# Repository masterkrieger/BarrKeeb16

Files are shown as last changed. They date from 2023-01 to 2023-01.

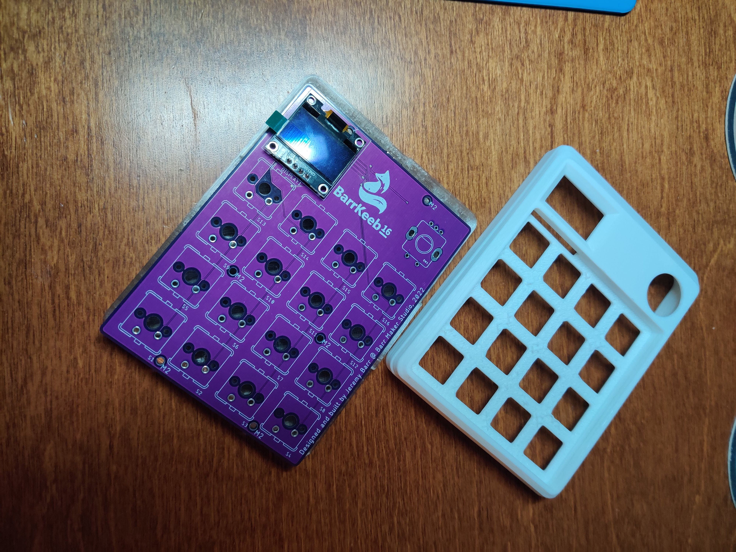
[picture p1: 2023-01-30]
Images/case_testing_fit.jpg

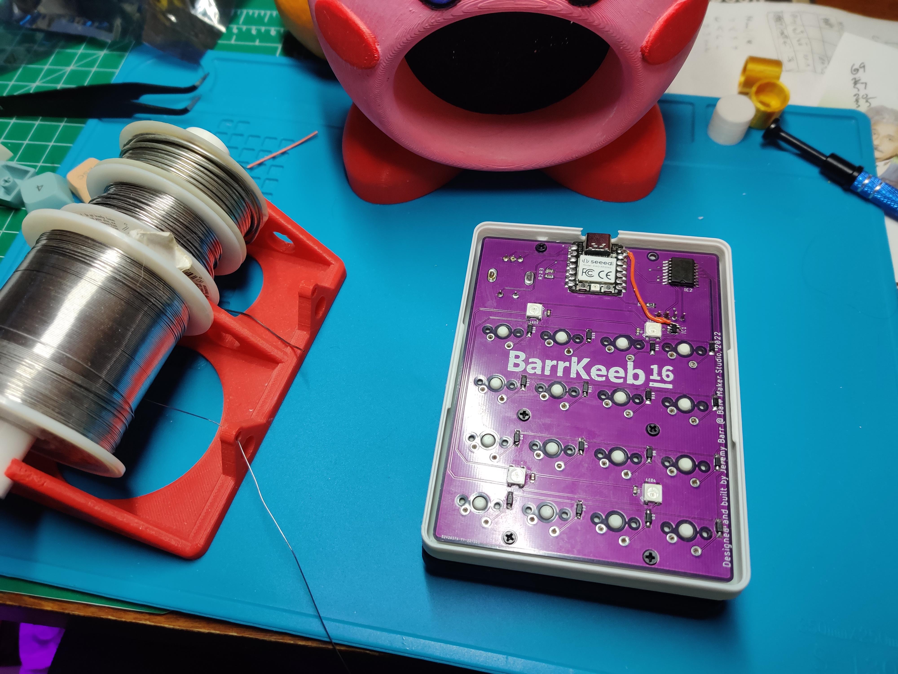
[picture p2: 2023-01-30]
Images/screwing_into_top_case.jpg

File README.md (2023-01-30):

# BarrKeeb16
 This is a 16 key macro keypad with a rotary encoder, OLED display and under-glow RGB. BarrKeeb16 is running KMK firmware on the Seeed XIAO RP2040.
 
BarrKeeb16_1
BarrKeeb16_2

# Parts
1. BarrKeeb16 custom PCB. [JLCPCB](https://jlcpcb.com/)
2. Seeed XIAO RP2040. [Digikey](https://www.digikey.com/en/products/detail/seeed-technology-co-ltd/102010428/14672129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) ― [SeeedStudio](https://www.seeedstudio.com/XIAO-RP2040-v1-0-p-5026.html)
3. 16 × Diodes (SOD-123) [Digikey](https://www.digikey.ca/en/products/detail/smc-diode-solutions/1N4148W/6022450)
4. 16 × Cherry MX style switches. [Digikey](https://www.digikey.ca/en/products/detail/adafruit-industries-llc/4952/14113453) ― [Adafruit](https://www.adafruit.com/product/4952)
5. 16 × DSA style keycaps. [Digikey](https://www.digikey.ca/en/products/detail/adafruit-industries-llc/4998/14552195) ― [Adafruit](https://www.adafruit.com/product/4998)
6. 1 × Encoder (PEC11R). [Digikey](https://www.digikey.ca/en/products/detail/bourns-inc/PEC11R-4215F-S0024/4499665) ― [Adafruit](https://www.adafruit.com/product/377)
7. 4 × Neopixel 5050 (SK6812 or WS2812 _ 5mm × 5mm) [Digikey](https://www.digikey.ca/en/products/detail/adafruit-industries-llc/1655/5154679) ― [Adafruit](https://www.adafruit.com/product/1655)
8. 4 × 0.1 µF Capacitors 0603 (1608 Metric). [Digikey](https://www.digikey.ca/en/products/detail/samsung-electro-mechanics/CL10B104KB8NNNL/3894274)
9. 1 × Level shifter SOT-23-5. [Digikey](https://www.digikey.ca/en/products/detail/texas-instruments/74AHCT1G125DBVTG4/1687957)
10. 1 × PCF8574 IO Expander. [Digikey](https://www.digikey.ca/en/products/detail/nxp-usa-inc/PCF8574T-3-512/735690)
10. 1 × 10 kOhms Resistor 0805 (2012 Metric). [Digikey](https://www.digikey.ca/en/products/detail/stackpole-electronics-inc/RMCF0805JG10K0/1757769)
10. 1 × 4.7 kOhms Resistor 0805 (2012 Metric). [Digikey](https://www.digikey.ca/en/products/detail/stackpole-electronics-inc/RMCF0805JT4K70/1757774)
11. 5 × Screws (M2 × 2.5mm)
12. 4 × Rubber Bumper Feet. [Adafruit](https://www.adafruit.com/product/550)

# OLED Image
 If you want to replace the BarrKeeb16_screenlogo bitmap, create any black and white 128x64 pixel image and rename as 'BarrKeeb16_screenlogo.bmp' or 'BarrKeeb16_screenlogo_inverted.bmp' or modify the image filename in [display_logo.py](https://github.com/masterkrieger/BarrKeeb16/blob/main/Firmware/display_logo.py).

## TODO:
- Update STL models with new OLED position (v1.2).
- Update FIRMWARE with new RP2040 and IO Expander pinouts (v1.2).

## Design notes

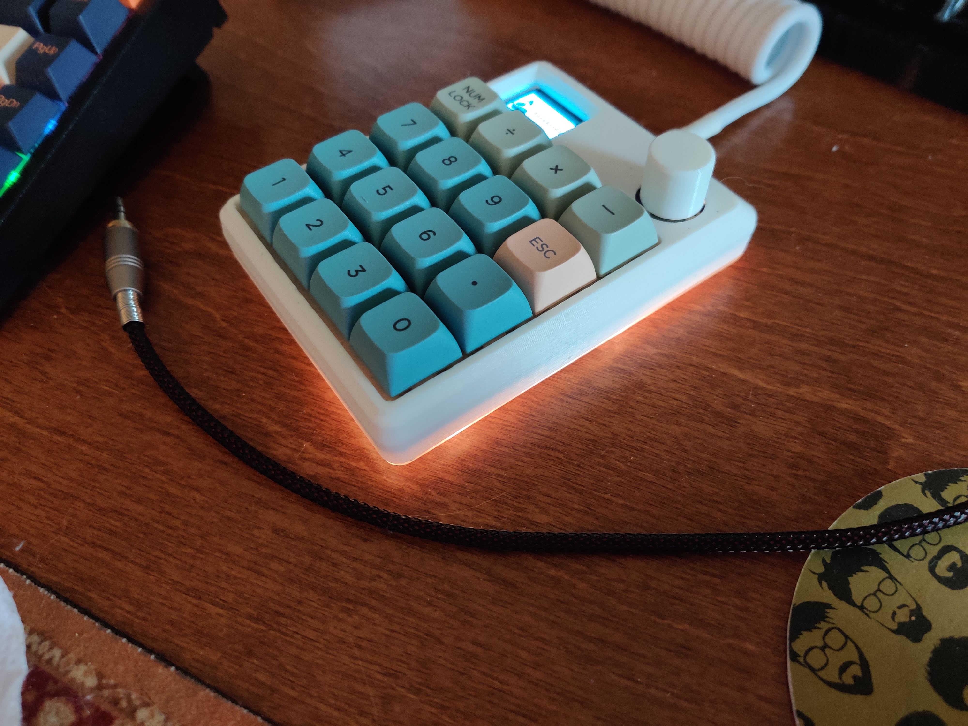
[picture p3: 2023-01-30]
Images/BarrKeeb16_2.jpg

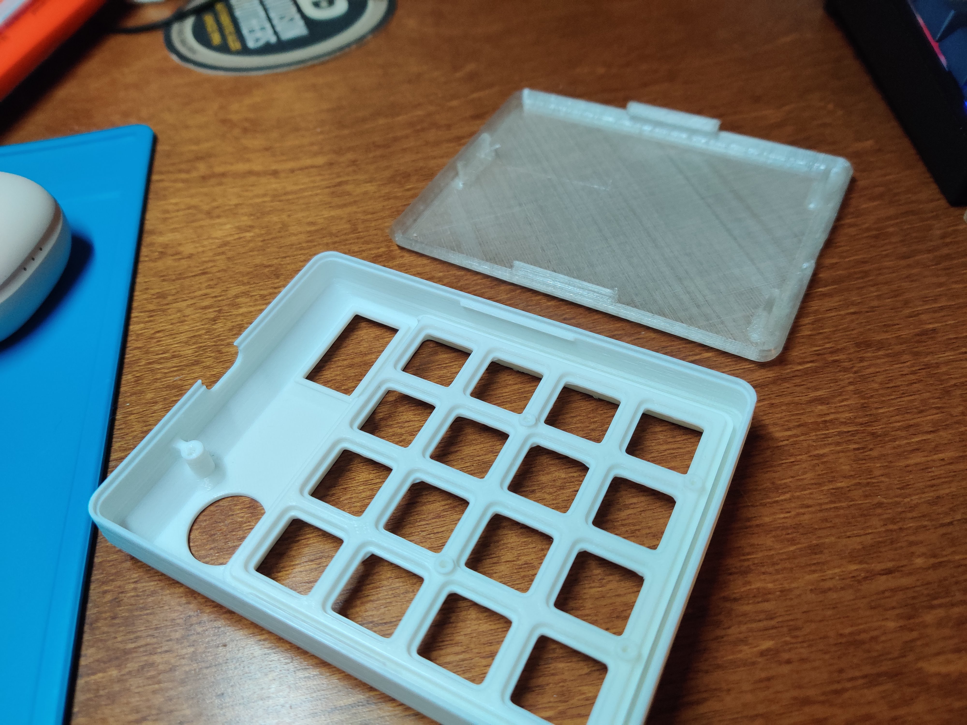
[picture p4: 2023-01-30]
Images/case_1.jpg

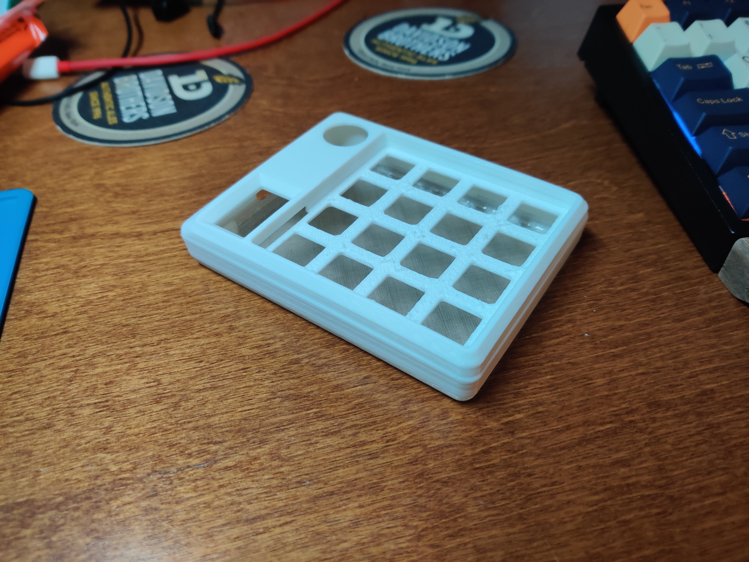
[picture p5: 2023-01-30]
Images/case_2.jpg

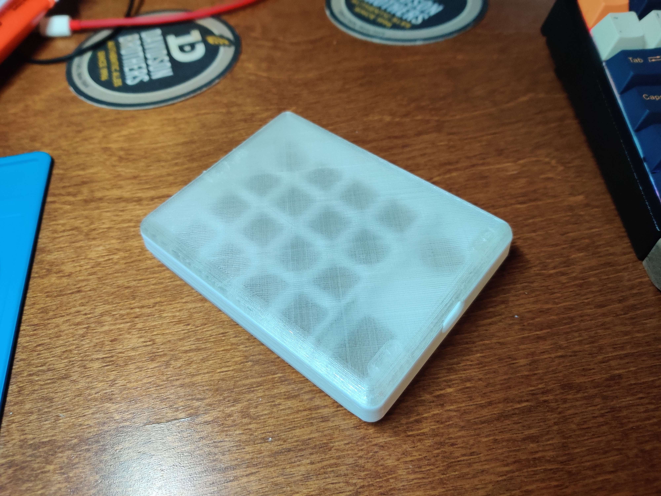
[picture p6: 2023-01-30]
Images/case_3.jpg

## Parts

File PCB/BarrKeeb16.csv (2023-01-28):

QTY | Value | Device | Package | Description | Digikey | QTY/Pack | Price | Link | Subtotal
4 | 0.1uF | 0.1UF-0603-25V-(+80/-20%) | 603 | 0.1µF ceramic capacitors | 276-CL10B104KB8NNNLCT-ND | 1 | 0.027 |  | 0.108
16 |  | MICROBUILDER_DIODESOD-123 | MICROBUILDER_SOD-123 | Diode | 1655-1360-1-ND | 1 | 0.124 |  | 1.984
1 | DIY-MODULES_DISPLAY-OLED-128X64-I2C | DIY-MODULES_DISPLAY-OLED-128X64-I2C | DIY-MODULES_DISPLAY-OLED-128X64-I2C | 128x64 Dot Matrix OLED Module based on SSD1306 chip | AOM12864A0-0.96WW-ANO | 1 | 1.35 | https://www.aliexpress.us/item/2251832770994631.html?_randl_shipto=US | 1.35
1 | 74HCT1G125DBV | 74AHC1G125DBV | SOT23-5 | Single Bus Buffer Gate with 3-State Output | 296-49526-1-ND | 1 | 0.95 |  | 0.95
1 | PCF8574T | PCF8574T | SO16W | I2C-Bus Remote 8-bit I/O expander | 568-1076-5-ND | 1 | 1.86 |  | 1.86
4 | WS2812B5050 | WS2812B5050 | WS2812B | NeoPixel 5050 RGB LED | 1528-2386-ND | 10 | 4.5 |  | 4.5
2 | 10K | R-US_R0805 | R0805 | RESISTOR, American symbol | RMCF0805JG10K0CT-ND | 1 | 0.018 |  | 0.036
1 | 4.7K | R-US_R0805 | R0805 | RESISTOR, American symbol | RMCF0805JG4K70CT-ND | 1 | 0.018 |  | 0.018
16 | CHERRY_MX | CHERRY_MX | CHERRY_MX | Cherry keymodule MX | 1528-4952-ND | 10 | 0.88 | https://www.aliexpress.us/item/3256803506501651.html?_randl_shipto=US | 1.76
1 |  | ADAFRUIT_ELECTROMECH_ENCODER_PLUS_SWITCH_BOURNS_PEC11 | ADAFRUIT_ELECTROMECH_PEC11+SWITCH | Rotary Encoder with Built-In Switch | PEC11R-4215F-S0024-ND | 1 | 1.88 |  | 1.88
1 | XIAO-RP2040 | XIAO-RP2040 | XIAO-SAMD21/RP2040-MODULE14P-2.54-21X17.8MM | Seeed Studio XIAO RP2040 v1.22 - Raspberry Pi RP2040 Microcontroller - 32-bit 133MHz Dual-Core ARM® Cortex® M0+processor Seeed SKU: 102010428 | 1597-102010428-ND | 1 | 5.4 | https://www.seeedstudio.com/XIAO-RP2040-v1-0-p-5026.html | 5.4
 |  |  |  |  |  |  |  | Total | 19.846

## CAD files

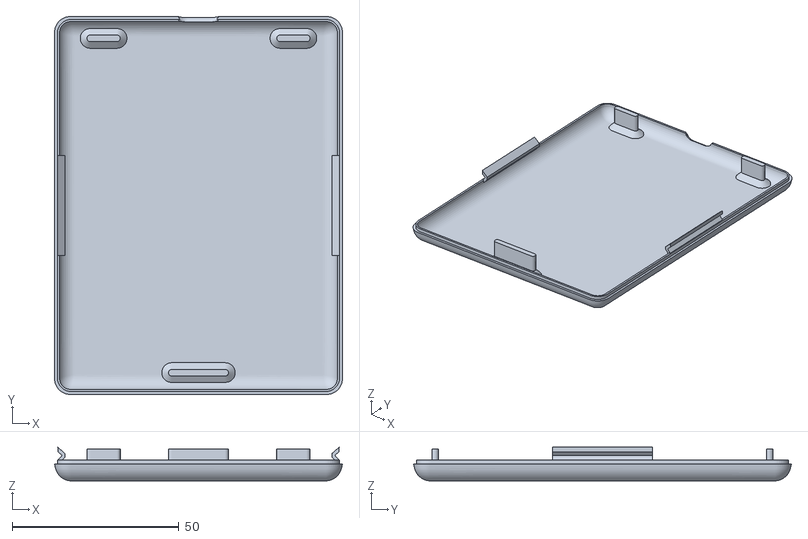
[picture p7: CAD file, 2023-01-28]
Models/BarrKeeb16_Bottom_Case.stl
86.4 x 113.4 x 10.1

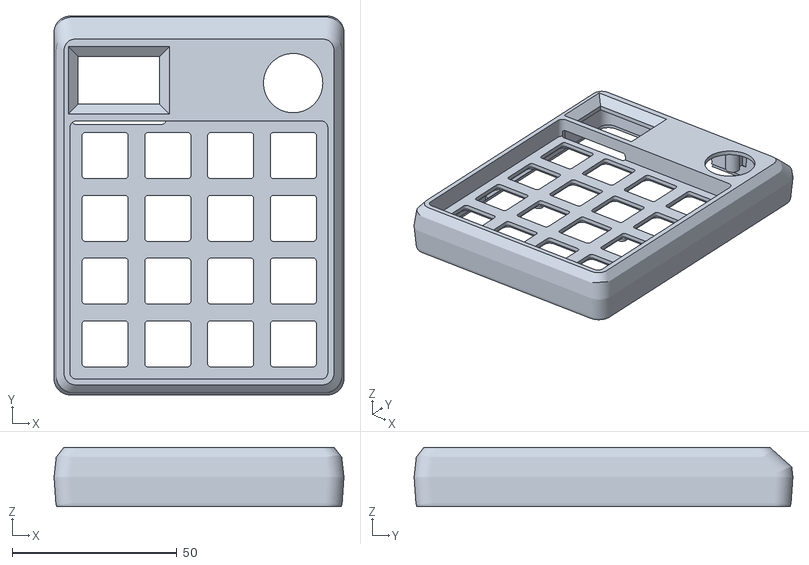
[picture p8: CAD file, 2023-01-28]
Models/BarrKeeb16_Top_Case.stl
88.0 x 115.0 x 18.0

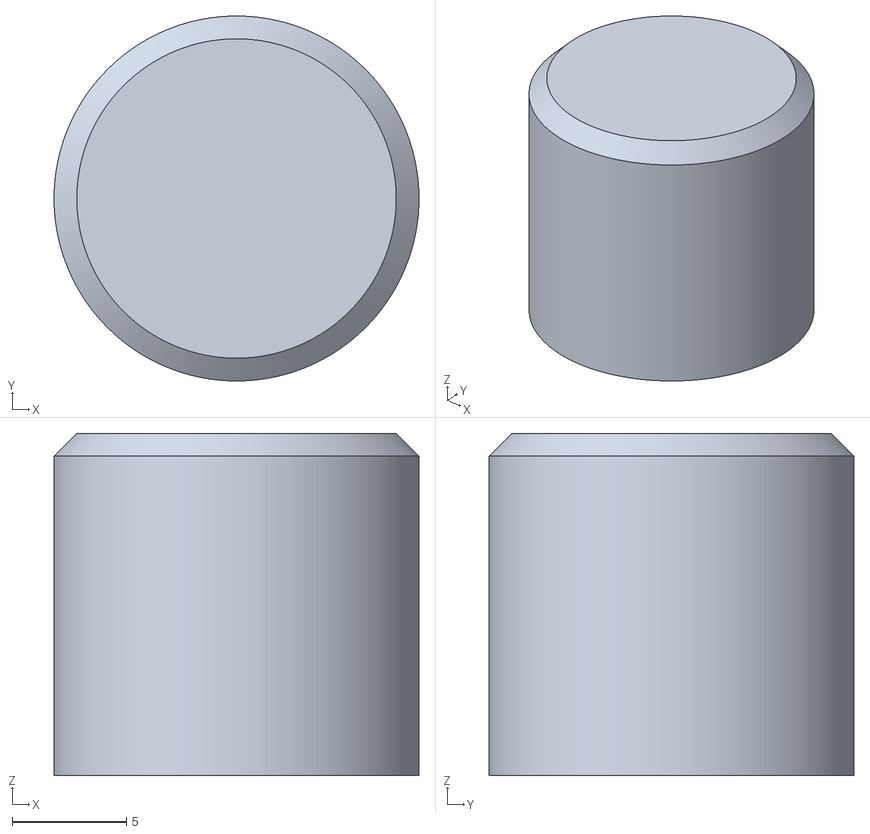
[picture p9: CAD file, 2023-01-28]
Models/Knob.stl
16.0 x 16.0 x 15.0

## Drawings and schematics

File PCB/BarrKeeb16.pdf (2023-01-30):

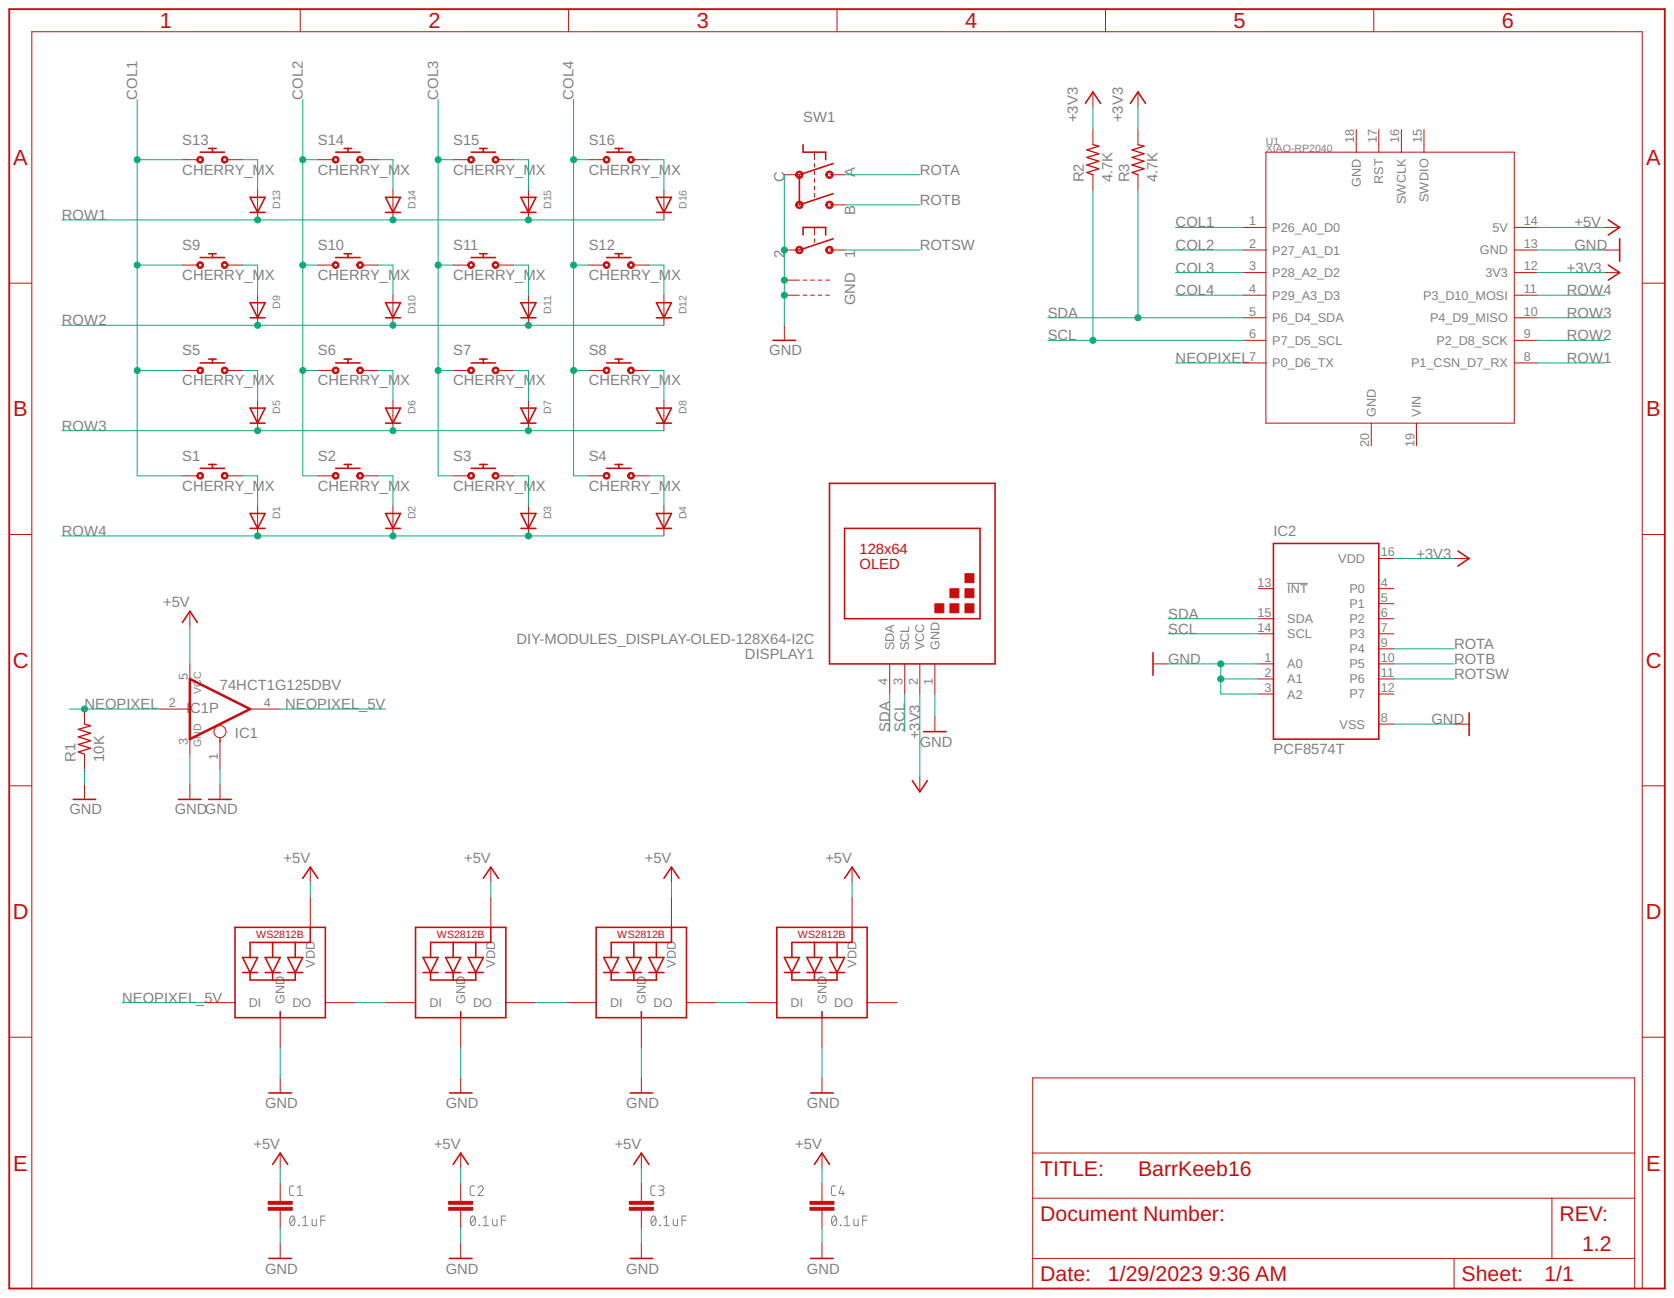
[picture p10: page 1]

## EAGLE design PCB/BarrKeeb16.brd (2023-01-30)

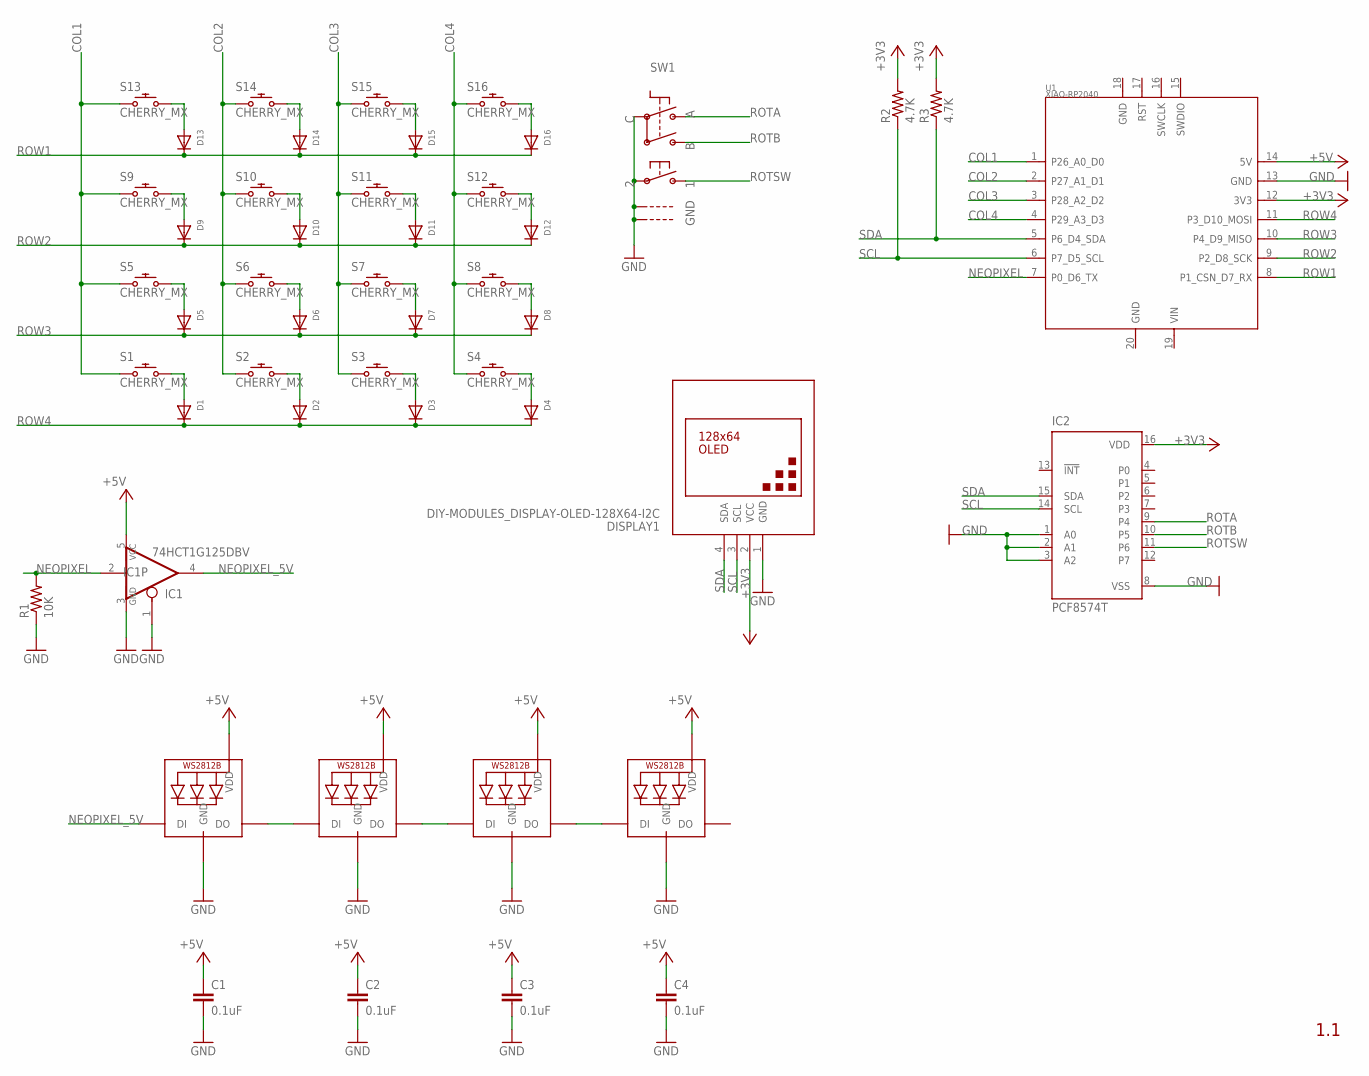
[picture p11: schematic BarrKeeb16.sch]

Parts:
C1, C2, C3, C4: 0.1uF; 0603
D1, D2, D3, D4, D5, D6, D7, D8, D9, D10, D11, D12, D13, D14, D15, D16: MICROBUILDER_DIODESOD-123; MICROBUILDER_SOD-123
DISPLAY1: DIY-MODULES_DISPLAY-OLED-128X64-I2C
IC1: 74HCT1G125DBV; SOT23-5
IC2: PCF8574T; SO16W
LED1, LED2, LED3, LED4: WS2812B5050; WS2812B
R1: 10K; R0805
R2, R3: 4.7K; R0805
S1, S2, S3, S4, S5, S6, S7, S8, S9, S10, S11, S12, S13, S14, S15, S16: CHERRY_MX
SW1: ADAFRUIT_ELECTROMECH_ENCODER_PLUS_SWITCH_BOURNS_P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; ADAFRUIT_ELECTROMECH_PEC11+SWITCH
U1: XIAO-RP2040; XIAO-SAMD21/RP2040-MODULE14P-2.54-21X17.8MM

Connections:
+3V3: DISPLAY1.2 (VCC), IC2.16 (VDD), R2.2, R3.2, U1.12 (3V3)
+5V: C1.1, C2.1, C3.1, C4.1, IC1.5 (VCC), LED1.1-VDD (VDD), LED2.1-VDD (VDD), LED3.1-VDD (VDD), LED4.1-VDD (VDD), U1.14 (5V)
COL1: S1.S1 (1), S5.S1 (1), S9.S1 (1), S13.S1 (1), U1.1 (P26_A0_D0)
COL2: S2.S1 (1), S6.S1 (1), S10.S1 (1), S14.S1 (1), U1.2 (P27_A1_D1)
COL3: S3.S1 (1), S7.S1 (1), S11.S1 (1), S15.S1 (1), U1.3 (P28_A2_D2)
COL4: S4.S1 (1), S8.S1 (1), S12.S1 (1), S16.S1 (1), U1.4 (P29_A3_D3)
GND: C1.2, C2.2, C3.2, C4.2, DISPLAY1.1 (GND), IC1.1 (OE), IC1.3 (GND), IC2.1 (A0), IC2.2 (A1), IC2.3 (A2), IC2.8 (VSS), LED1.3-GND (GND), LED2.3-GND (GND), LED3.3-GND (GND), LED4.3-GND (GND), R1.1, SW1.P$2, SW1.P$C, SW1.P$GND1, SW1.P$GND2, U1.13 (GND)
unnamed: D13.A, S13.S2 (2)
unnamed: D14.A, S14.S2 (2)
unnamed: LED1.2-DOUT (DO), LED2.4-DIN (DI)
unnamed: LED2.2-DOUT (DO), LED3.4-DIN (DI)
unnamed: LED3.2-DOUT (DO), LED4.4-DIN (DI)
unnamed: D15.A, S15.S2 (2)
unnamed: D16.A, S16.S2 (2)
unnamed: D9.A, S9.S2 (2)
unnamed: D10.A, S10.S2 (2)
unnamed: D11.A, S11.S2 (2)
unnamed: D12.A, S12.S2 (2)
unnamed: D5.A, S5.S2 (2)
unnamed: D6.A, S6.S2 (2)
unnamed: D7.A, S7.S2 (2)
unnamed: D8.A, S8.S2 (2)
unnamed: D1.A, S1.S2 (2)
unnamed: D2.A, S2.S2 (2)
unnamed: D3.A, S3.S2 (2)
unnamed: D4.A, S4.S2 (2)
NEOPIXEL: IC1.2 (I), R1.2, U1.7 (P0_D6_TX)
NEOPIXEL_5V: IC1.4 (O), LED1.4-DIN (DI)
ROTA: IC2.9 (P4), SW1.P$A
ROTB: IC2.10 (P5), SW1.P$B
ROTSW: IC2.11 (P6), SW1.P$1
ROW1: D13.C, D14.C, D15.C, D16.C, U1.8 (P1_CSN_D7_RX)
ROW2: D9.C, D10.C, D11.C, D12.C, U1.9 (P2_D8_SCK)
ROW3: D5.C, D6.C, D7.C, D8.C, U1.10 (P4_D9_MISO)
ROW4: D1.C, D2.C, D3.C, D4.C, U1.11 (P3_D10_MOSI)
SCL: DISPLAY1.3 (SCL), IC2.14 (SCL), R2.1, U1.6 (P7_D5_SCL)
SDA: DISPLAY1.4 (SDA), IC2.15 (SDA), R3.1, U1.5 (P6_D4_SDA)

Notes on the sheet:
1.1

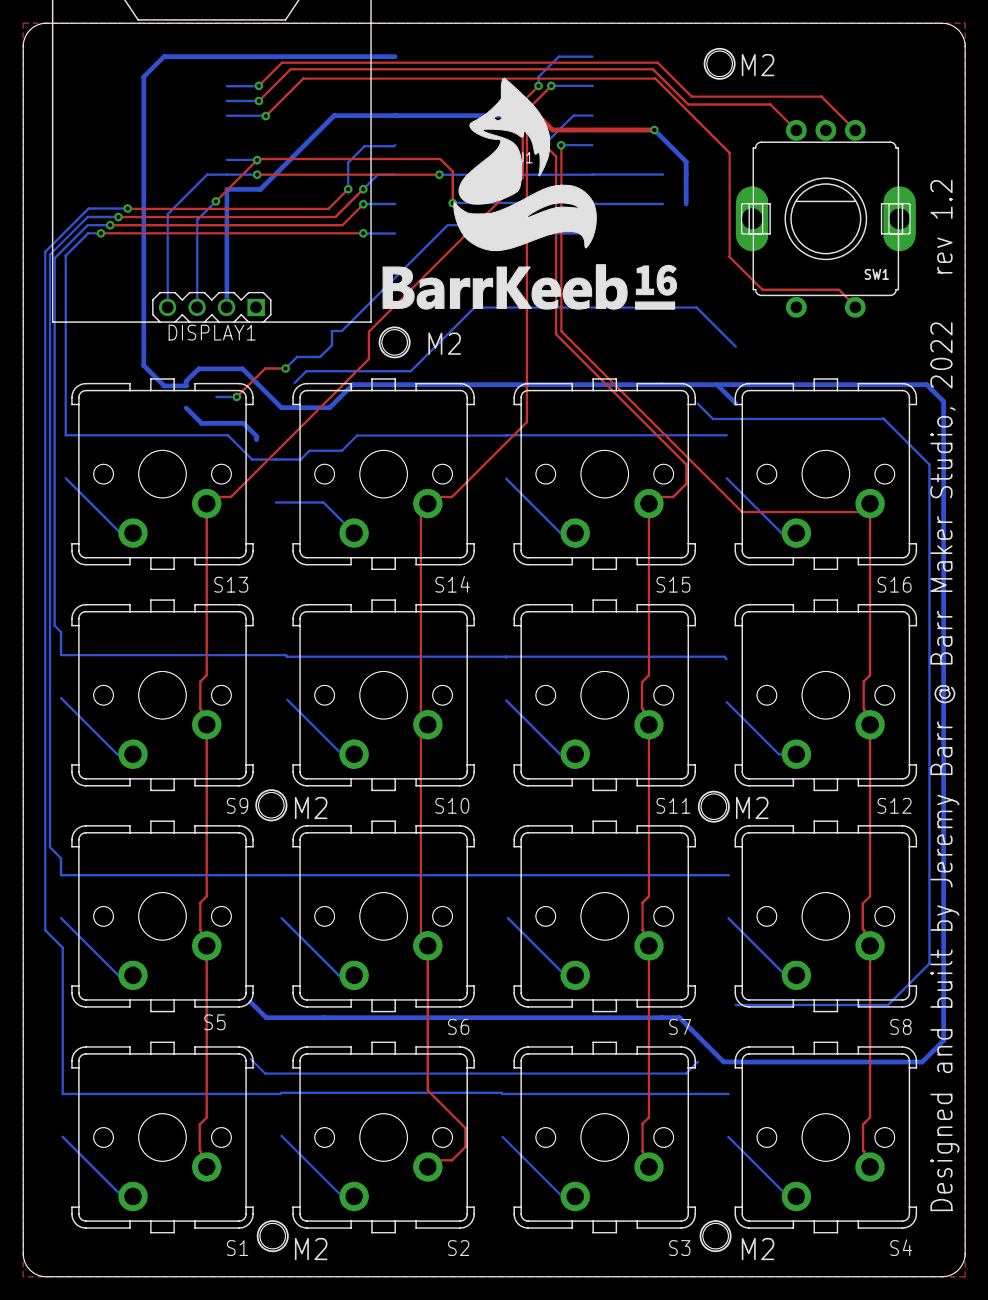
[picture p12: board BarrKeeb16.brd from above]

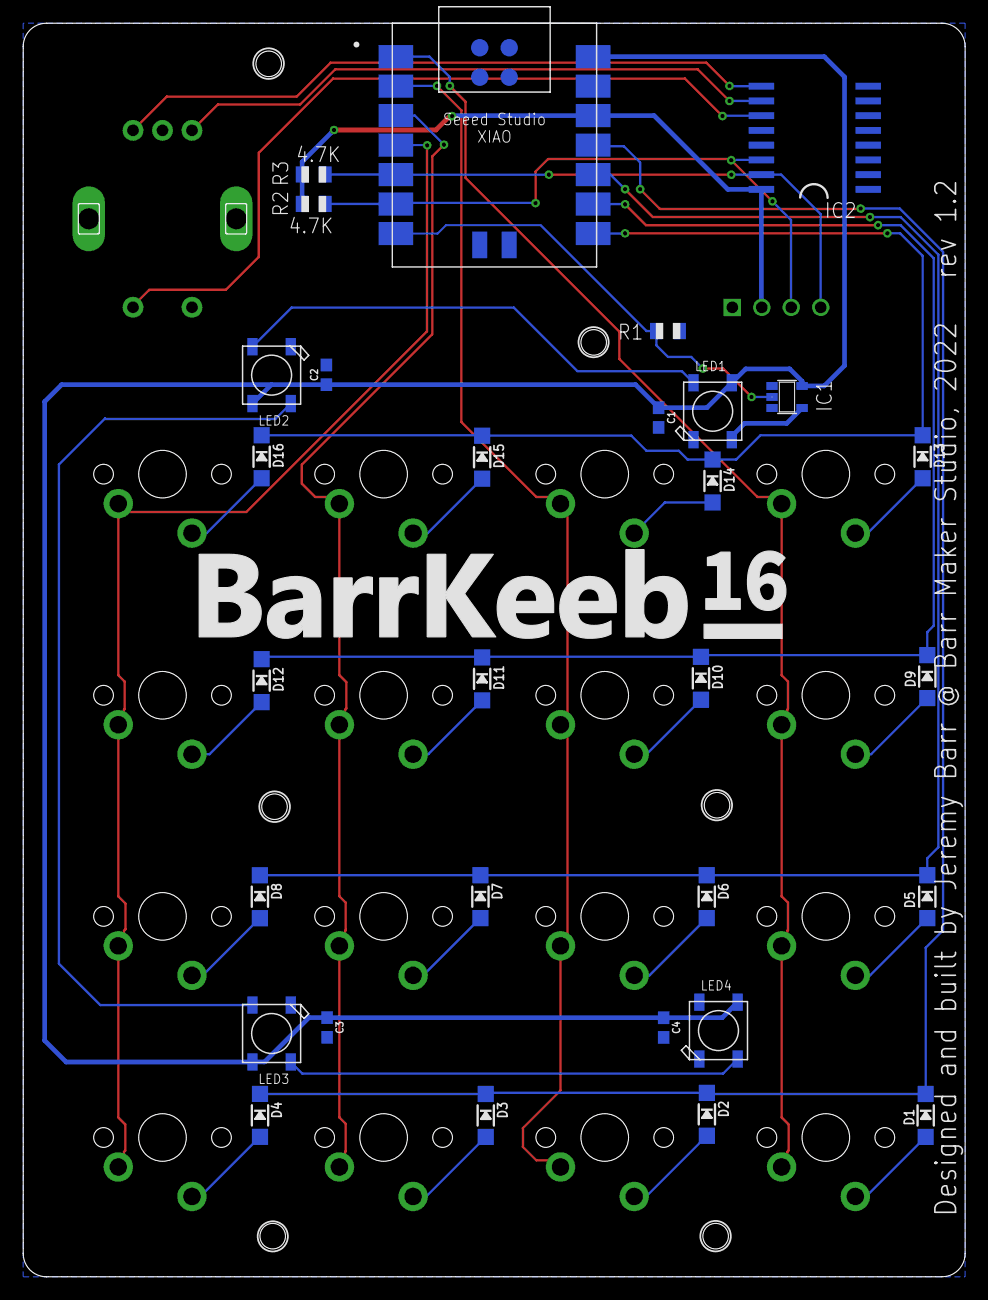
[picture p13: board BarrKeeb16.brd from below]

Board: 2 copper layers, 81.2 x 108.0 mm, 50 parts (31 on the bottom side), 37 nets.

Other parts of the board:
U$1: BARRKEEP16-LOGO
U$2: BARRKEEB-16

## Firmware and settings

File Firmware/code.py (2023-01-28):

######################
#  BarrKeeb16
#  version 1.0
#  28-Dec-2022
#  Author: Jeremy Barr
#
#  Notes:
#  kmk.matrix modified for PCF8574 output LOW when polling columns.
#  PCF8574 modified to read pin value as opposite value. KMK reads pin HIGH as keypress, but that's default input value.
######################

#print("Starting")

import board
import displayio

import adafruit_pcf8574  # modded library to work with KMK
import adafruit_displayio_ssd1306

import terminalio
import neopixel
from adafruit_display_text import label
from display_logo import display_splash_fox_inverted

from kmk.kmk_keyboard import KMKKeyboard
from kmk.keys import KC
from kmk.matrix import DiodeOrientation
from kmk.handlers.sequences import send_string, simple_key_sequence
from kmk.modules.layers import Layers as _Layers
from kmk.modules.encoder import EncoderHandler
from kmk.modules.tapdance import TapDance
from kmk.extensions.media_keys import MediaKeys
from kmk.extensions.RGB import RGB

# init IO Expander
pcf = adafruit_pcf8574.PCF8574(board.I2C(), address=0x20)

# KEYBOARD SETUP
#layers = Layers()
keyboard = KMKKeyboard()
encoders = EncoderHandler()
tapdance = TapDance()
tapdance.tap_time = 250
keyboard.modules = [encoders, tapdance]

# SWITCH MATRIX
keyboard.col_pins = (pcf.get_pin(4), pcf.get_pin(5), pcf.get_pin(6), pcf.get_pin(7))
keyboard.row_pins = (pcf.get_pin(0), pcf.get_pin(1), pcf.get_pin(2), pcf.get_pin(3))
keyboard.diode_orientation = DiodeOrientation.ROWS

# ENCODERS
encoders.pins = ((board.A0, board.A1, board.A2, False),)

# EXTENSIONS
rgb_ext = RGB(pixel_pin = board.D3, num_pixels=4)#, hue_default=100)
keyboard.extensions = [rgb_ext, MediaKeys()]

# custom functions
class Layers(_Layers):
    last_top_layer = 0
    hues = (4, 20, 69)
    
    def after_hid_send(keyboard):
        print(keyboard.active_layers[0])
        if keyboard.active_layers[0] != self.last_top_layer:
            self.last_top_layer = keyboard.active_layers[0]
            rgb.set_hsv_fill(self.hues[self.last_top_layer], 255, 255)
            display_layer_text(keyboard.active_layers[0])
            #print(keyboard.active_layers[0])
            
keyboard.modules.append(Layers())

keyboard.debug_enabled = False

# MACROS Layer 1
WIN_RIGHT = simple_key_sequence([KC.LGUI(KC.RIGHT), KC.MACRO_SLEEP_MS(100), KC.ESC])
WIN_LEFT = simple_key_sequence([KC.LGUI(KC.LEFT), KC.MACRO_SLEEP_MS(100), KC.ESC])
WIN_UP = simple_key_sequence([KC.LGUI(KC.UP)])
WIN_MIN = simple_key_sequence([KC.LGUI(KC.M)])
WIN_MAX = simple_key_sequence([KC.LGUI(KC.LSFT(KC.M))])
DESK_RIGHT = simple_key_sequence([KC.LCMD(KC.LCTRL(KC.RIGHT))])
DESK_LEFT = simple_key_sequence([KC.LCMD(KC.LCTRL(KC.LEFT))])
WIN_TAB = simple_key_sequence([KC.LCMD(KC.TAB)])
COPY = KC.LCTRL(KC.C)
PASTE = KC.LCTRL(KC.V)
POWERSHELL = simple_key_sequence([KC.LCMD(KC.R), KC.MACRO_SLEEP_MS(250), send_string('powershell'), KC.ENTER])

# NEOPIXEL RGB
#RGB_COLORS = KC.TD(Color.RED, Color.GREEN, Color.BLUE, Color.WHITE, Color.YELLOW, Color.ORANGE)
#TODO: change to NEOPIXEL functions
# Color_RED = rgb_ext.set_hsv_fill(0,100,100)
# Color_BLUE = rgb_ext.set_hsv_fill(240,100,100)
# Color_MAGENTA = rgb_ext.set_hsv_fill(300,100,100)
# Color_ORANGE = rgb_ext.set_hsv_fill(30,100,100)
# Color_WHITE = rgb_ext.set_hsv_fill(0,0,100)
# Color_GREEN = rgb_ext.set_hsv_fill(120,100,100)

_______ = KC.TRNS
xxxxxxx = KC.NO

# LAYER SWITCHING TAP DANCE
#TD_LYRS_1 = KC.TD(KC.KP_ENTER, KC.TO(1), KC.TO(2), KC.TO(0))
TD_LYRS_0 = KC.TD(KC.KP_ENTER, KC.TO(0))
TD_LYRS_1 = KC.TD(KC.KP_ENTER, KC.TO(1))
TD_LYRS_2 = KC.TD(KC.KP_ENTER, KC.TO(2))
RGB_LYRS = KC.TD(KC.RGB_MODE_PLAIN, KC.RGB_MODE_SWIRL, KC.RGB_MODE_KNIGHT, KC.RGB_MODE_RAINBOW, KC.RGB_MODE_BREATHE_RAINBOW)

# KEYMAPS
keyboard.keymap = [
    [  # Layer 0: WIN MACROS
        TD_LYRS_1, POWERSHELL,   WIN_TAB,    RGB_LYRS,
        WIN_UP,    KC.MPRV,      KC.MNXT,    KC.MPLY,
        WIN_LEFT,  WIN_RIGHT,    WIN_MIN,    WIN_MAX,
        COPY,      PASTE,        DESK_LEFT,  DESK_RIGHT ,
    ],
    [  # Layer 1: NUMPAD
        TD_LYRS_2,   KC.KP_SLASH,   KC.KP_ASTERISK,   KC.KP_MINUS,
        KC.P7,       KC.P8,         KC.P9,            KC.KP_PLUS,
        KC.P4,       KC.P5,         KC.P6,            KC.PDOT,
        KC.P1,       KC.P2,         KC.P3,            KC.P0,
    ],
    [  # Layer 2: RGB CTL
        TD_LYRS_0,          KC.RGB_HUI,          KC.RGB_VAI,                   KC.RGB_ANI,
        KC.RGB_SAI,         KC.RGB_HUD,          KC.RGB_VAD,                   KC.RGB_AND,    
        KC.RGB_MODE_SWIRL,  KC.RGB_MODE_KNIGHT,  KC.RGB_MODE_BREATHE_RAINBOW,  KC.RGB_SAI,
        KC.RGB_MODE_PLAIN,  KC.RGB_MODE_BREATHE, KC.RGB_MODE_RAINBOW,          KC.RGB_SAD,    
    ],
]

encoders.map = [    ((KC.VOLD, KC.VOLU, KC.MUTE),),   # MEDIA
                    ((KC.VOLD, KC.VOLU, KC.MUTE),),   # MEDIA
                    ((KC.RGB_AND, KC.RGB_ANI, KC.RGB_TOG),),   # RGB
                ]

#print("Keyboard Go!")
display_splash_fox_inverted()
if __name__ == '__main__':
    keyboard.go()

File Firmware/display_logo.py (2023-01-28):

import board
import time
import displayio
import adafruit_displayio_ssd1306

displayio.release_displays()

SCREEN_WIDTH = 128 # OLED display width, in pixels
SCREEN_HEIGHT = 64 # OLED display height, in pixels

# Create the OLED display object
display = adafruit_displayio_ssd1306.SSD1306(
    displayio.I2CDisplay(board.I2C(), device_address=0x3C),
    width=SCREEN_WIDTH,
    height=SCREEN_HEIGHT,
    rotation=180
)

def display_splash_fox():
    # Create a new display group
    group = displayio.Group()
    
    # Create a bitmap from the image file
    bitmap = displayio.OnDiskBitmap('BarrKeeb16_screenlogo.bmp')
    
    # Create a palette with 2 colors (black and white)
    palette = displayio.Palette(2)
    palette[0] = 0x000000
    palette[1] = 0xFFFFFF

    # Create a TileGrid to hold the bitmap
    color_converter = displayio.ColorConverter()
    tilegrid = displayio.TileGrid(bitmap, pixel_shader=bitmap.pixel_shader)
    # Add the tilegrid to the group
    group.append(tilegrid)

    # Set the group as the display's root
    display.show(group)
    #print("Display Logo")

def display_splash_fox_inverted():
    # Create a new display group
    group = displayio.Group()
    
    # Create a bitmap from the image file
    bitmap = displayio.OnDiskBitmap('BarrKeeb16_screenlogo_inverted.bmp')
    
    # Create a palette with 2 colors (black and white)
    palette = displayio.Palette(2)
    palette[0] = 0x000000
    palette[1] = 0xFFFFFF

    # Create a TileGrid to hold the bitmap
    color_converter = displayio.ColorConverter()
    tilegrid = displayio.TileGrid(bitmap, pixel_shader=bitmap.pixel_shader)
    # Add the tilegrid to the group
    group.append(tilegrid)

    # Set the group as the display's root
    display.show(group)
    #print("Display Logo Inverted")

def display_layer_text(layer):
    displaytext= {0:"Layer 0",1:"Layer 1",2:"Layer 2"}
    return displaytext.get(layer, "no layer")

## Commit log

2023-01-28 Init Upload
    Working code v1.0
    [Case Top Test v1.stl, Knob.stl, Macropad_BMS.brd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]
2023-01-30 v1.2 - swapped keys and encoder pinout
    - Moved keyswitches to the RP2040
    - Moved encoder to PCF8574 IO Expander
    - Updated EAGLE schematic and board to incorporate new routing layout.
    [BarrKeeb16.brd, BarrKeeb16.csv, BarrKeeb16.sch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]

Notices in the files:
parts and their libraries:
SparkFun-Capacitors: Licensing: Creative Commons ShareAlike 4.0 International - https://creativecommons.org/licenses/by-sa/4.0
